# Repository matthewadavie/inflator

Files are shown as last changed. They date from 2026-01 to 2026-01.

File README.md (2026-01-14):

# Inflator V3
## Background
I like four wheel driving. I dislike having to sit in the sun to inflate my tyres manually.

Unfortunately the only option (commercially) is on the order of > $300. That is excessive. It can be cheaper.

## Requirements
* Input Voltage: 6V - 18V (nominal)
* Input Voltage: 4V - 30V (transient)
* Functions:
  - HSD/FET gate drive for compressor control & solenoid activation
  - ESP32 for wireless comms (originally wanted STM32 but decided that I would rather control the pressure from webapp on phone)
  - OLED to display pressure readings

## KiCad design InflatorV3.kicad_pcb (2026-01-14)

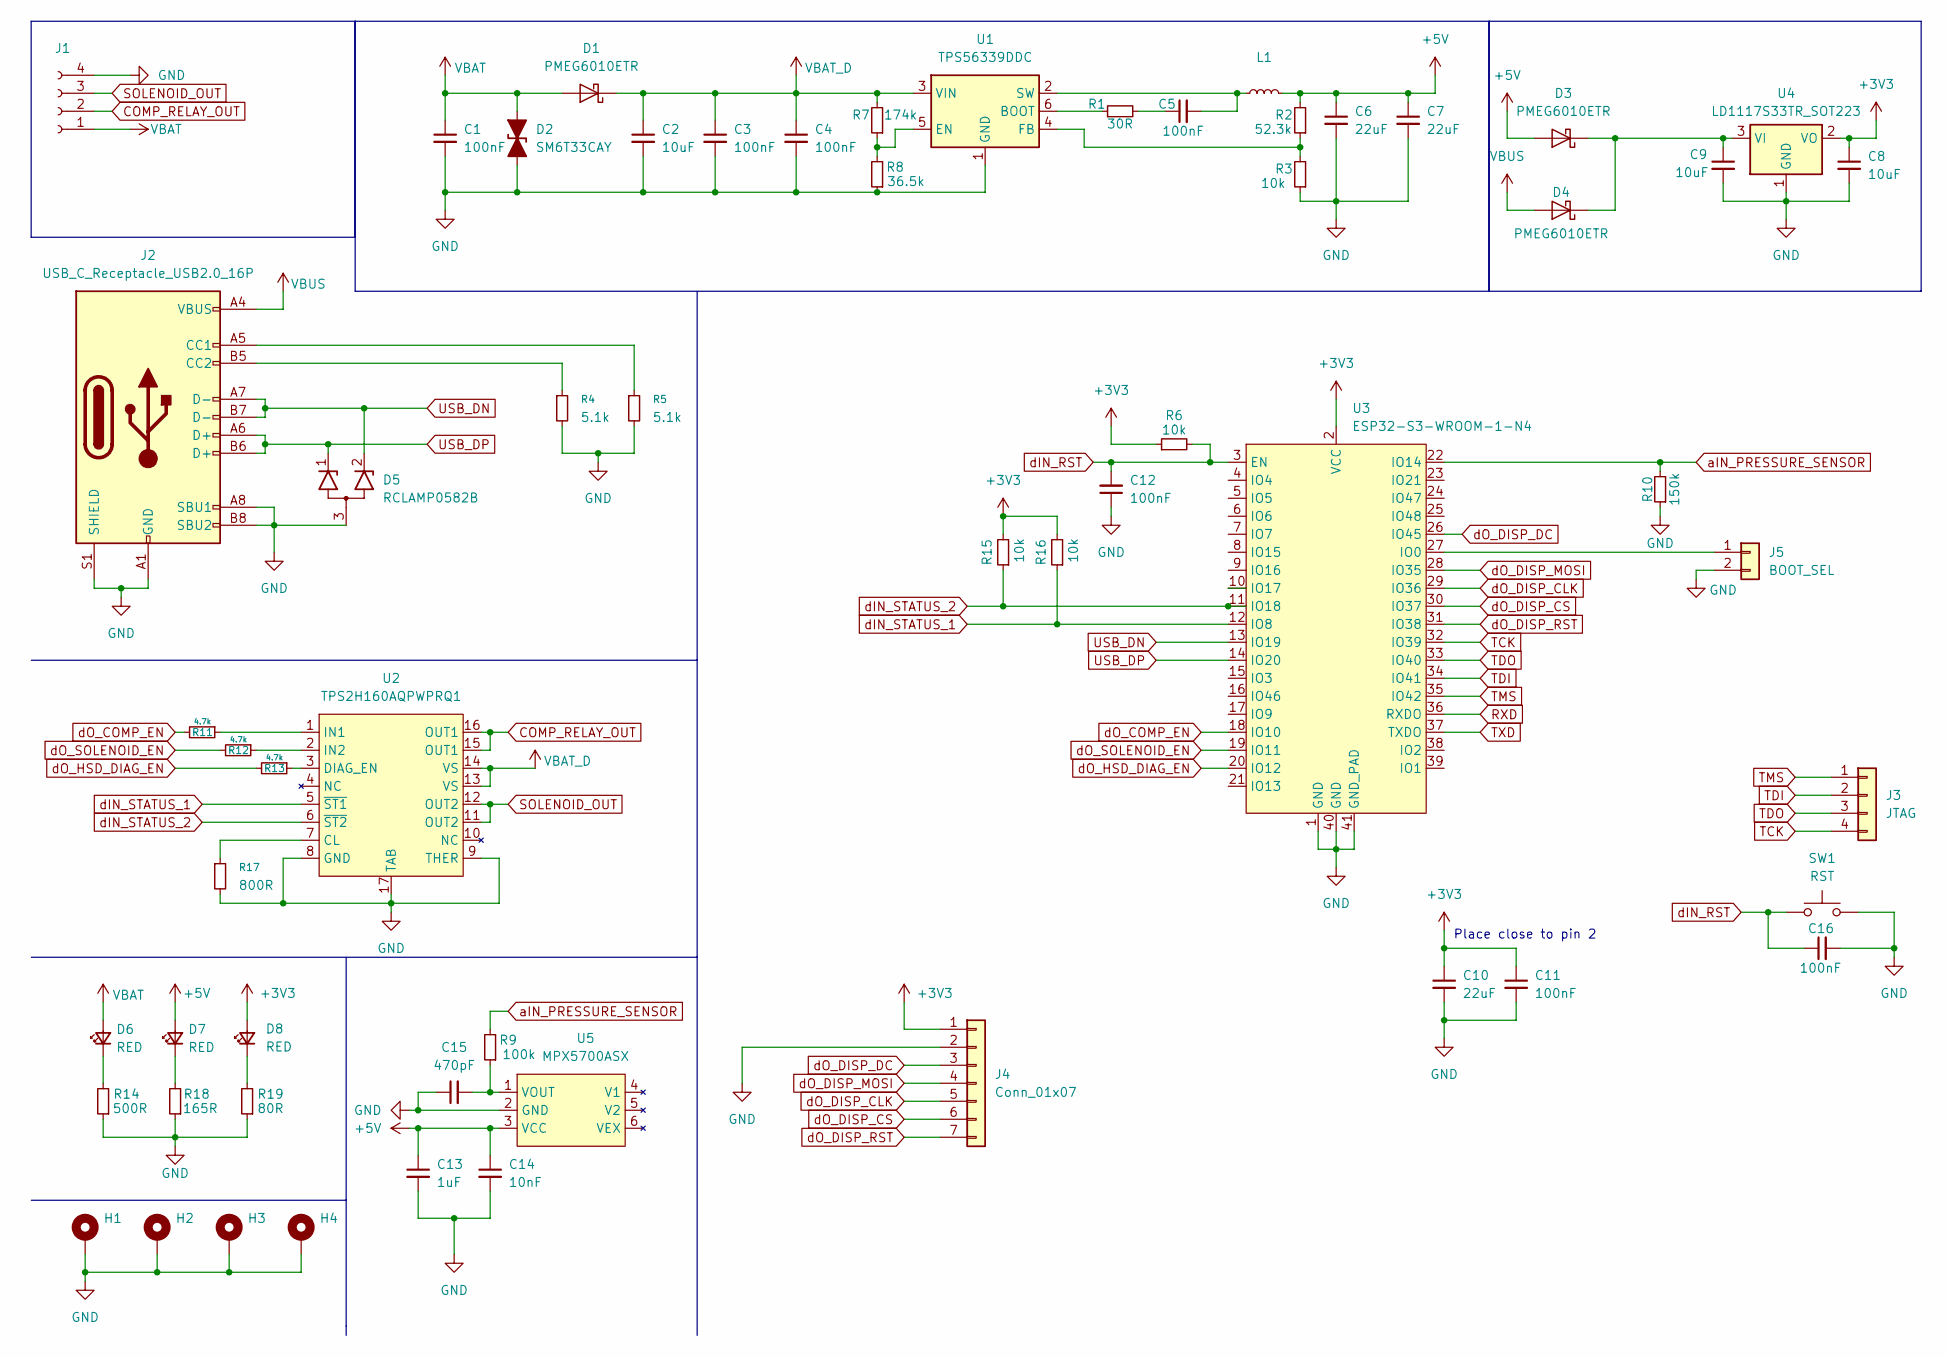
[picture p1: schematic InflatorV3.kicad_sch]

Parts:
C1, C11, C12: 100nF; C_1206_3216Metric_Pad1.33x1.80mm_HandSolder
C2: 10uF; C_1206_3216Metric_Pad1.33x1.80mm_HandSolder
C3, C4, C5, C16: 100nF; C_0805_2012Metric_Pad1.18x1.45mm_HandSolder
C6, C7, C10: 22uF; C_1206_3216Metric_Pad1.33x1.80mm_HandSolder
C8, C9: 10uF; C_0805_2012Metric_Pad1.18x1.45mm_HandSolder
C13: 1uF; C_0805_2012Metric_Pad1.18x1.45mm_HandSolder
C14: 10nF; C_0805_2012Metric_Pad1.18x1.45mm_HandSolder
C15: 470pF; C_0805_2012Metric_Pad1.18x1.45mm_HandSolder
D1, D3, D4: PMEG6010ETR; D_SOD-123F
D2: SM6T33CAY; D_SMB_Handsoldering
D5: RCLAMP0582B; SOT-416
D6, D7, D8: RED; LED_0805_2012Metric_Pad1.15x1.40mm_HandSolder
H1, H2, H3, H4: MountingHole_Pad; MountingHole_3.2mm_M3_DIN965_Pad_TopBottom
J1: Molex_Micro-Fit_3.0_43650-0400_1x04_P3.00mm_Horizontal
J2: USB_C_Receptacle_USB2.0_16P; USB_C_Receptacle_GCT_USB4105-xx-A_16P_TopMnt_Horizontal
J3: JTAG; PinHeader_1x04_P2.54mm_Vertical
J4: Conn_01x07; SM07B-GHS-TB
J5: BOOT_SEL; PinHeader_1x02_P2.54mm_Vertical
L1: 5.6uH; IHLP-2020; MPN IHLP2020CZER5R6M01
R1: 30R; R_0805_2012Metric_Pad1.20x1.40mm_HandSolder
R2: 52.3k; R_0805_2012Metric_Pad1.20x1.40mm_HandSolder
R3, R6, R15, R16: 10k; R_0805_2012Metric_Pad1.20x1.40mm_HandSolder
R4, R5: 5.1k; R_0805_2012Metric_Pad1.20x1.40mm_HandSolder
R7: 174k; R_0805_2012Metric_Pad1.20x1.40mm_HandSolder
R8: 36.5k; R_0805_2012Metric_Pad1.20x1.40mm_HandSolder
R9: 100k; R_0805_2012Metric_Pad1.20x1.40mm_HandSolder
R10: 150k; R_0805_2012Metric_Pad1.20x1.40mm_HandSolder
R11, R12, R13: 4.7k; R_0805_2012Metric_Pad1.20x1.40mm_HandSolder
R14: 500R; R_0805_2012Metric_Pad1.20x1.40mm_HandSolder
R17: 800R; R_0805_2012Metric_Pad1.20x1.40mm_HandSolder
R18: 165R; R_0805_2012Metric_Pad1.20x1.40mm_HandSolder
R19: 80R; R_0805_2012Metric_Pad1.20x1.40mm_HandSolder
SW1: RST; PTS526; MPN PTS526SM15SMTR2 LFS
U1: TPS56339DDC; SOT-23-6
U2: TPS2H160AQPWPRQ1; HTSSOP-16-1EP_4.4x5mm_P0.65mm_EP3.4x5mm_Mask2.66x2.46mm; MPN TPS2H160AQPWPRQ1
U3: ESP32-S3-WROOM-1-N4; ESP32-S3-WROOM-1; MPN ESP32-S3-WROOM-1-N4
U4: LD1117S33TR_SOT223; SOT-223-3_TabPin2
U5: MPX5700ASX; MPN MPX5700ASX

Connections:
+3V3: C8.1, C10.1, C11.1, D8.2 (A), J4.1, R6.1, R15.2, R16.2, U3.2 (VCC), U4.2 (VO)
+5V: C6.1, C7.1, C13.1, C14.1, D3.2 (A), D7.2 (A), L1.2, R2.2, U5.3 (VCC)
COMP_RELAY_OUT: J1.2, U2.15 (OUT1), U2.16 (OUT1)
GND: C1.2, C2.2, C3.2, C4.2, C6.2, C7.2, C8.2, C9.2, C10.2, C11.2, C12.1, C13.2, C14.2, C15.1, C16.2, D2.1 (A1), D5.3 (A), H1.1, H2.1, H3.1, H4.1, J1.4, J2.A1 (GND), J2.A8 (SBU1), J2.A12 (GND), J2.B1 (GND), J2.B8 (SBU2), J2.B12 (GND), J2.S1 (SHIELD), J4.2, J5.2, R3.1, R4.2, R5.2, R8.1, R10.1, R14.1, R17.2, R18.1, R19.1, SW1.2, U1.1 (GND), U2.8 (GND), U2.9 (THER), U2.17 (TAB), U3.1 (GND), U3.40 (GND), U3.41 (GND_PAD), U4.1 (GND), U5.2 (GND)
unnamed: C5.1, R1.2
unnamed: C9.1, D3.1 (K), D4.1 (K), U4.3 (VI)
unnamed: D6.1 (K), R14.2
unnamed: D7.1 (K), R18.2
unnamed: D8.1 (K), R19.2
unnamed: J2.A5 (CC1), R5.1
unnamed: J2.B5 (CC2), R4.1
unnamed: J5.1, U3.27 (IO0)
unnamed: R1.1, U1.6 (BOOT)
unnamed: R7.1, R8.2, U1.5 (EN)
unnamed: R2.1, R3.2, U1.4 (FB)
unnamed: C5.2, L1.1, U1.2 (SW)
unnamed: R17.1, U2.7 (CL)
unnamed: R13.1, U2.3 (DIAG_EN)
unnamed: R11.1, U2.1 (IN1)
unnamed: R12.1, U2.2 (IN2)
unnamed: C15.2, R9.1, U5.1 (VOUT)
RXD: U3.36 (RXDO)
SOLENOID_OUT: J1.3, U2.11 (OUT2), U2.12 (OUT2)
TCK: J3.4, U3.32 (IO39)
TDI: J3.2, U3.34 (IO41)
TDO: J3.3, U3.33 (IO40)
TMS: J3.1, U3.35 (IO42)
TXD: U3.37 (TXDO)
USB_DN: D5.2 (K2), J2.A7 (D-), J2.B7 (D-), U3.13 (IO19)
USB_DP: D5.1 (K1), J2.A6 (D+), J2.B6 (D+), U3.14 (IO20)
VBAT: C1.1, D1.2 (A), D2.2 (A2), D6.2 (A), J1.1
VBAT_D: C2.1, C3.1, C4.1, D1.1 (K), R7.2, U1.3 (VIN), U2.13 (VS), U2.14 (VS)
VBUS: D4.2 (A), J2.A4 (VBUS), J2.A9 (VBUS), J2.B4 (VBUS), J2.B9 (VBUS)
aIN_PRESSURE_SENSOR: R9.2, R10.2, U3.22 (IO14)
dIN_RST: C12.2, C16.1, R6.2, SW1.1, U3.3 (EN)
dIN_STATUS_1: R16.1, U2.5 (~ST1), U3.12 (IO8)
dIN_STATUS_2: R15.1, U2.6 (~ST2), U3.11 (IO18)
dO_COMP_EN: R11.2, U3.18 (IO10)
dO_DISP_CLK: J4.5, U3.29 (IO36)
dO_DISP_CS: J4.6, U3.30 (IO37)
dO_DISP_DC: J4.3, U3.26 (IO45)
dO_DISP_MOSI: J4.4, U3.28 (IO35)
dO_DISP_RST: J4.7, U3.31 (IO38)
dO_HSD_DIAG_EN: R13.2, U3.20 (IO12)
dO_SOLENOID_EN: R12.2, U3.19 (IO11)

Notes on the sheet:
Place close to pin 2

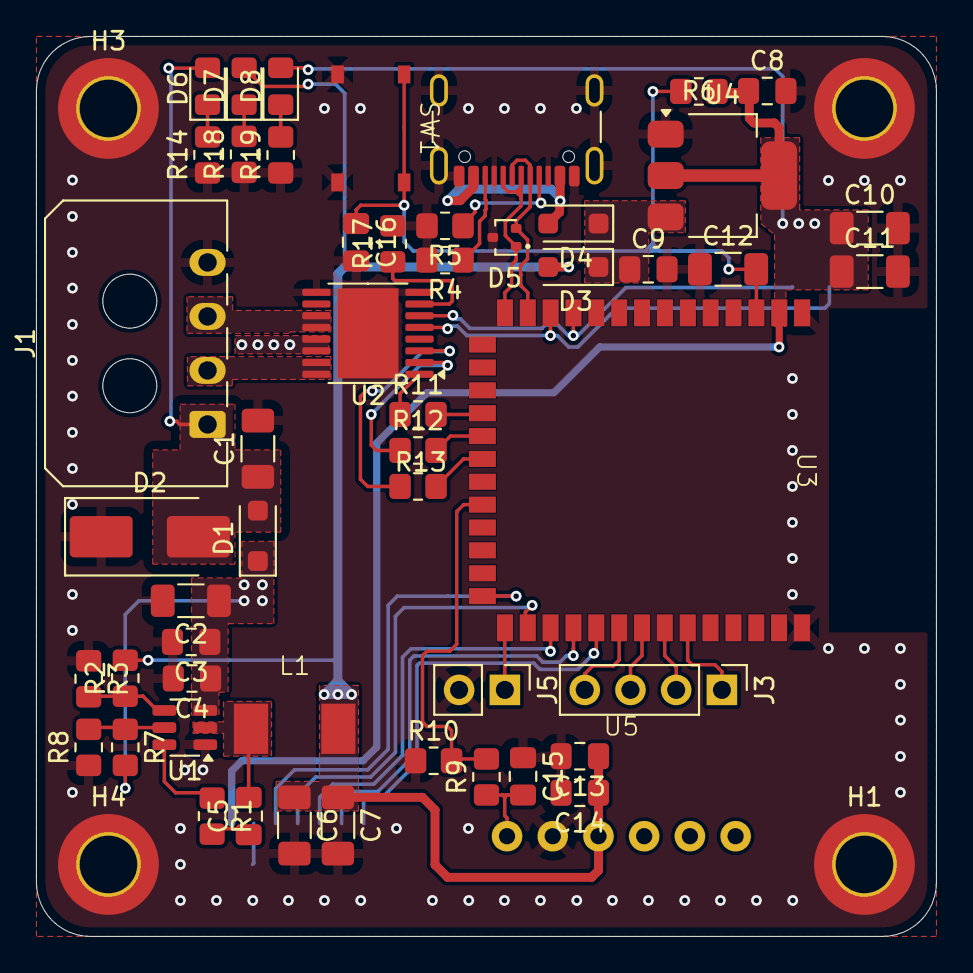
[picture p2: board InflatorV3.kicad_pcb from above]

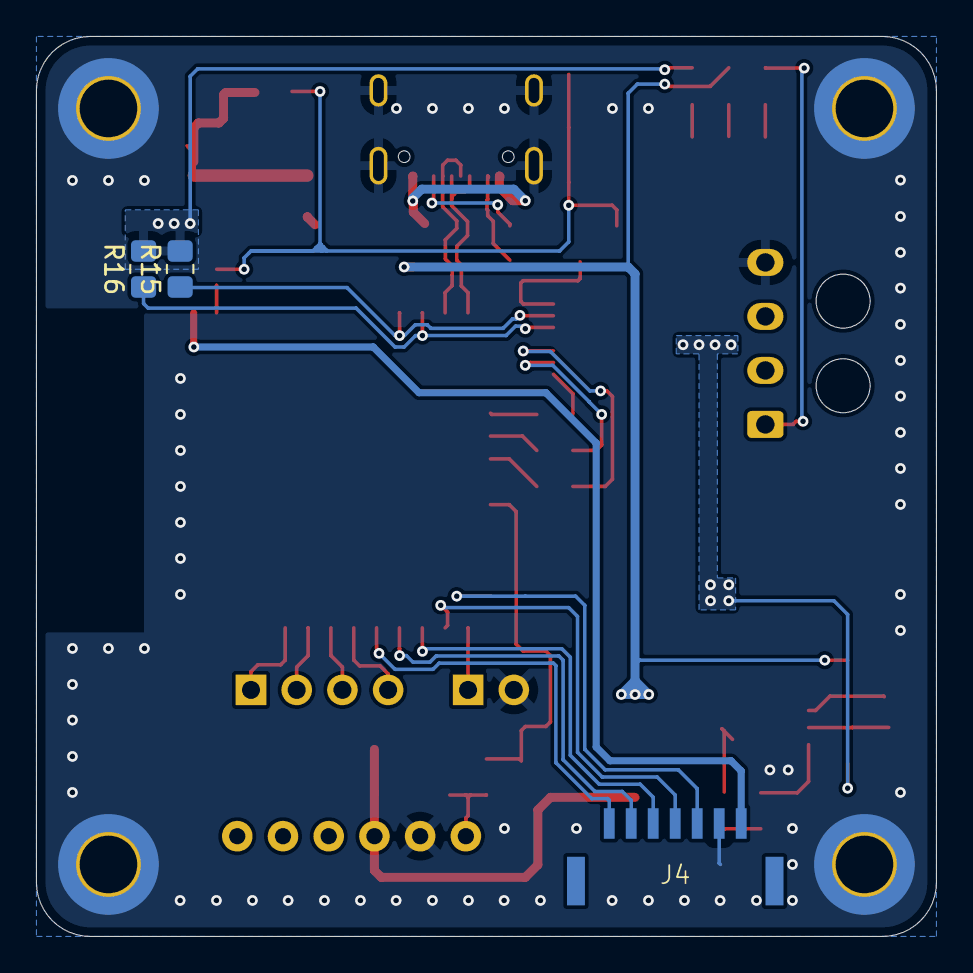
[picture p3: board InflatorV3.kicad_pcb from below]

Board: 2 copper layers, 50.0 x 50.0 mm, 59 parts (3 on the bottom side), 43 nets.
